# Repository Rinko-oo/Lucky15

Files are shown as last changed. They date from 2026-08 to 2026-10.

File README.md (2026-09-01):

# Lucky15
15 key + rotary encoder macropad for media control and macros

## CAD


## PCB



## Schematic


## BOM
This is everything needed to build the Lucky15, currently all available on AliExpress\
**NOTE** - Welcome deal was applied to the Milky Yellow switches
| Qty | Part | Link | Cost (CAD) |
| --- | ---- | ---- | --- |
| 1 | NRF52840 | [Link](https://www.aliexpress.com/item/1005007205026373.html) | $6.09 |
| 15 | Gateron Milky Yellow Switches | [Link](https://www.aliexpress.com/item/1005007039372956.html) | $1.41 |
| 1 | Polymer Lithium Battery 600mAh | [Link](https://www.aliexpress.com/item/1005007905669396.html) | $11.58 |
| 1 | 0.91 Inch OLED Display | [Link](https://www.aliexpress.com/item/1005008640108394.html) | $3.54 |
| 16 | 1N4148 Diodes | [Link](https://www.aliexpress.com/item/1005009379098965.html) | $4.29 |
| 2 | 2.54mm Silver Headers | [Link](https://www.aliexpress.com/item/4001122376295.html) | $3.79 |
| 15 | Blank Keycaps | [Link](https://www.aliexpress.com/item/1005007683242914.html) | $8.79 |
| 1 | EC11 Rotary Encoder | [Link](https://www.aliexpress.com/item/1005004908084537.html) | $6.24 |
| 1 | PCB | [Link](https://jlcpcb.com/) | $11.18 |
| 1 | MSK12C02 Switch | [Link](https://www.aliexpress.com/item/4000685483225.html) | $3.59 |
|  |  | **Total** | **$60.50** |

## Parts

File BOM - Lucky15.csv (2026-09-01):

Item | Link | Price
NRF52840 | https://www.aliexpress.com/item/1005007205026373.html?mp=1 | $6.09
Gateron Milky Yellow Switches (50 Pcs) | https://www.aliexpress.com/item/1005007039372956.html?mp=1 | $1.41
Polymer Lithium Battery 600mAh | https://www.aliexpress.com/item/1005007905669396.html?mp=1 | $11.58
0.91 Inch OLED Display | https://www.aliexpress.com/item/1005008640108394.html?mp=1 | $3.54
1N4148 Diodes (50 Pcs) | https://www.aliexpress.com/item/1005009379098965.html?mp=1 | $4.29
2.54mm Silver Headers | https://www.aliexpress.com/item/4001122376295.html?mp=1 | $3.79
Blank Keycaps (20 Pcs) | https://www.aliexpress.com/item/1005007683242914.html?mp=1 | $8.79
EC11 Rotary Encoder (5 Pcs) | https://www.aliexpress.com/item/1005004908084537.html?mp=1 | $6.24
PCB | https://cart.jlcpcb.com/shopcart/cart/ | $11.18
MSK12C02 Switch (50 Pcs) | https://www.aliexpress.com/item/4000685483225.html | $3.59
Total |  | $60.50

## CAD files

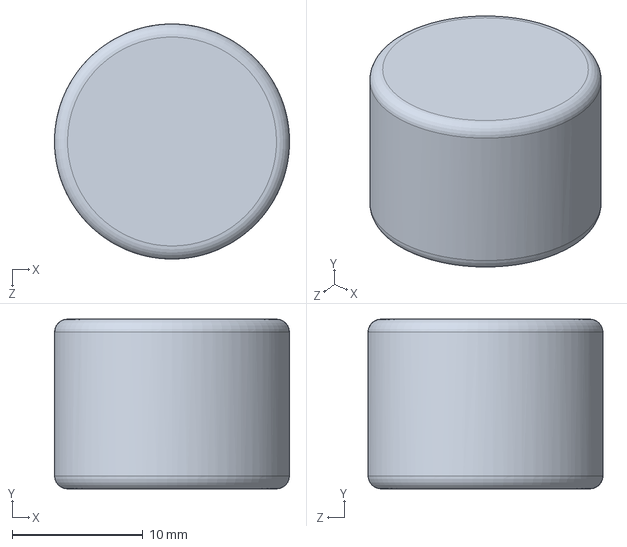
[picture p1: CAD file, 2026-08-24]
cad/spookynob.SLDPRT
18.0 x 13.0 x 18.0 mm

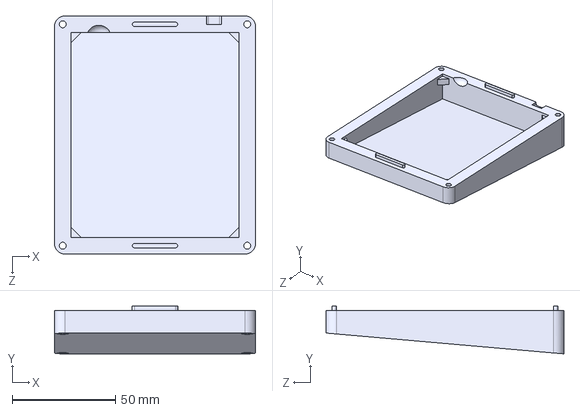
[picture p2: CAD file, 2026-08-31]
production/Case Bottom.STEP
97.2 x 23.1 x 115.0 mm

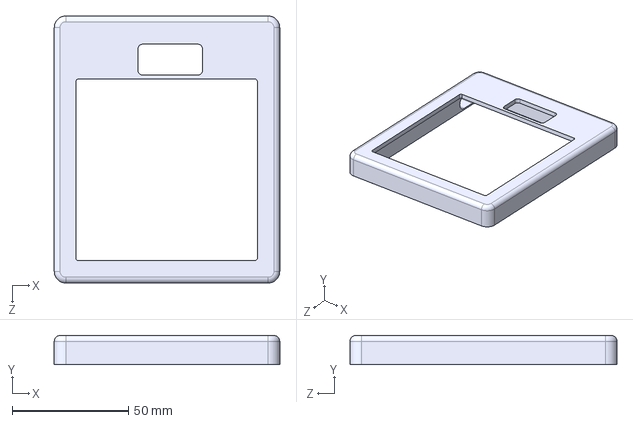
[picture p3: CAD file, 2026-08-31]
production/Case Top.STEP
97.2 x 12.5 x 115.0 mm

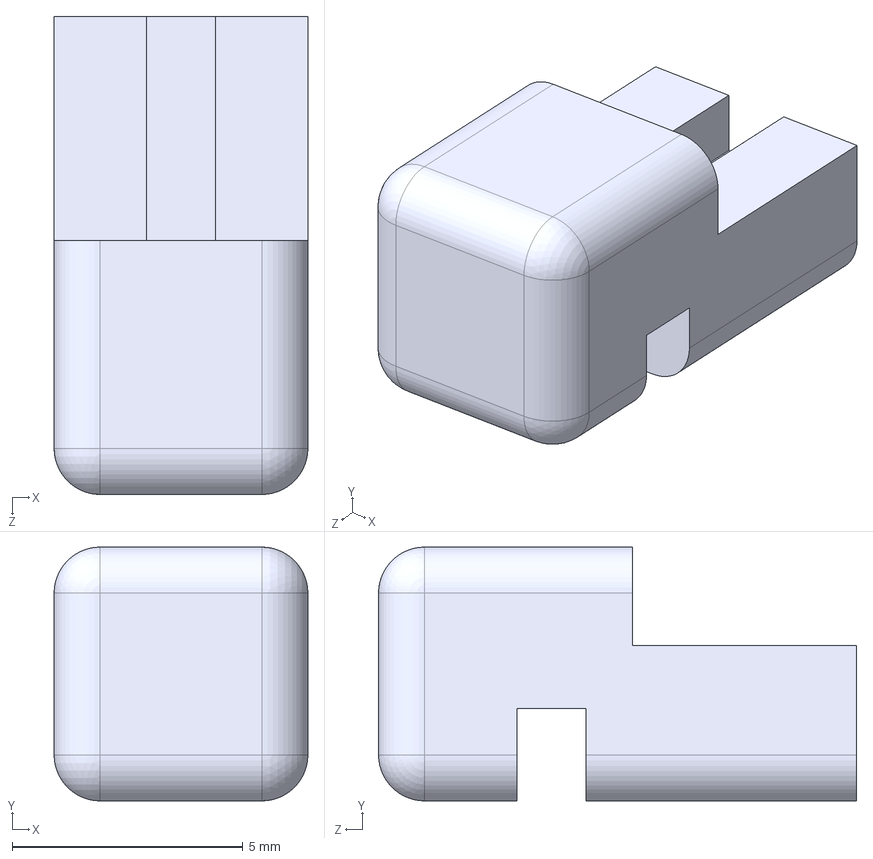
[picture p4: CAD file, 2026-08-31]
production/Power Switch.STEP
5.50 x 5.50 x 10.4 mm

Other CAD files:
production/spookynob.STEP

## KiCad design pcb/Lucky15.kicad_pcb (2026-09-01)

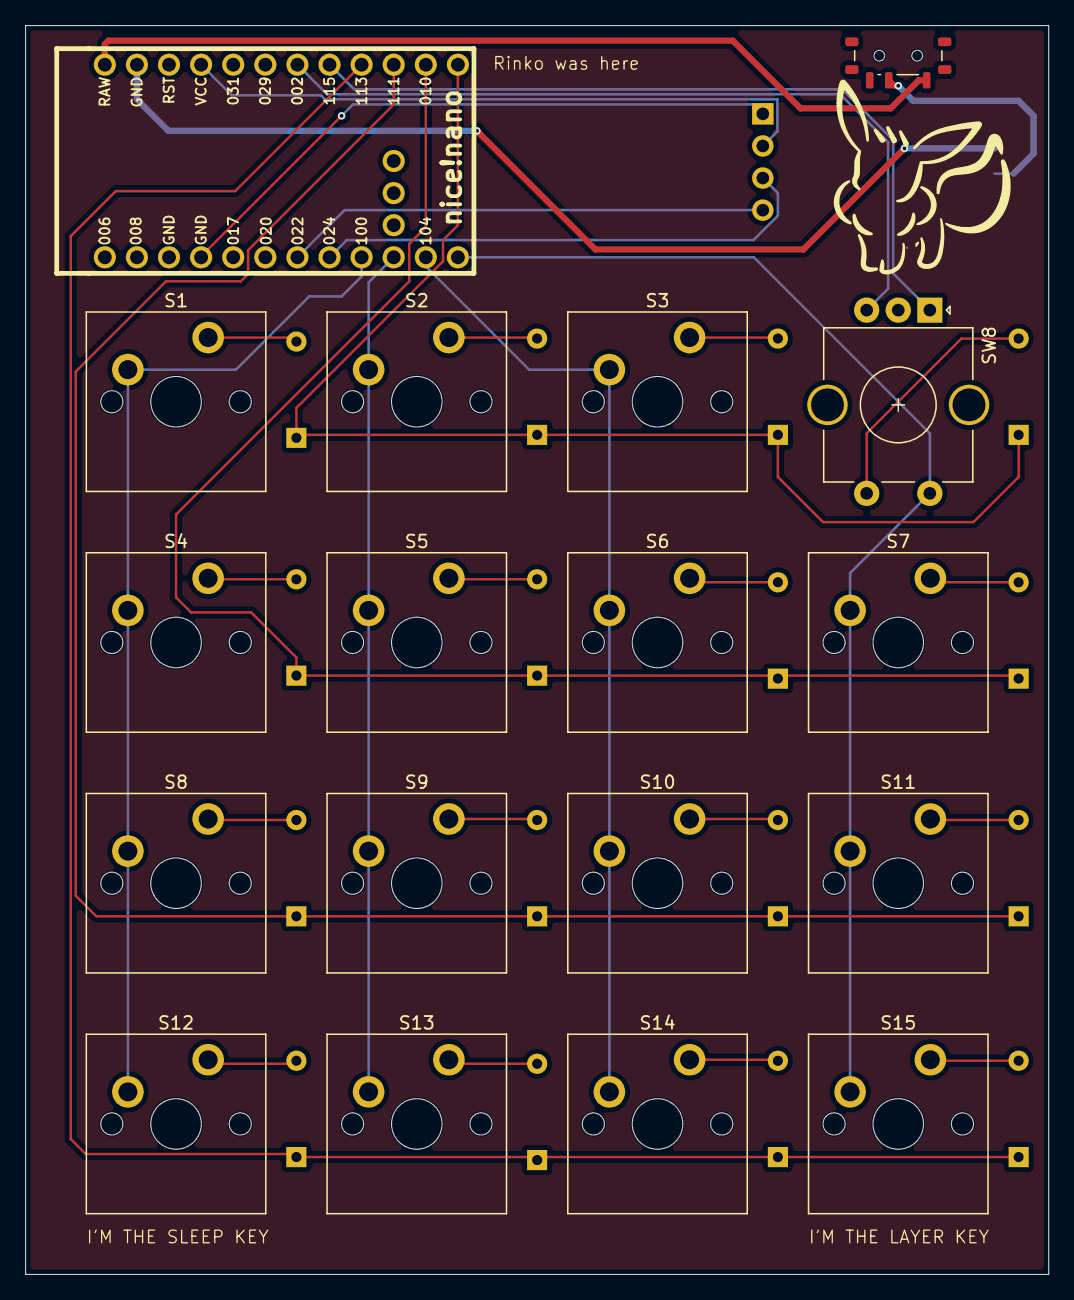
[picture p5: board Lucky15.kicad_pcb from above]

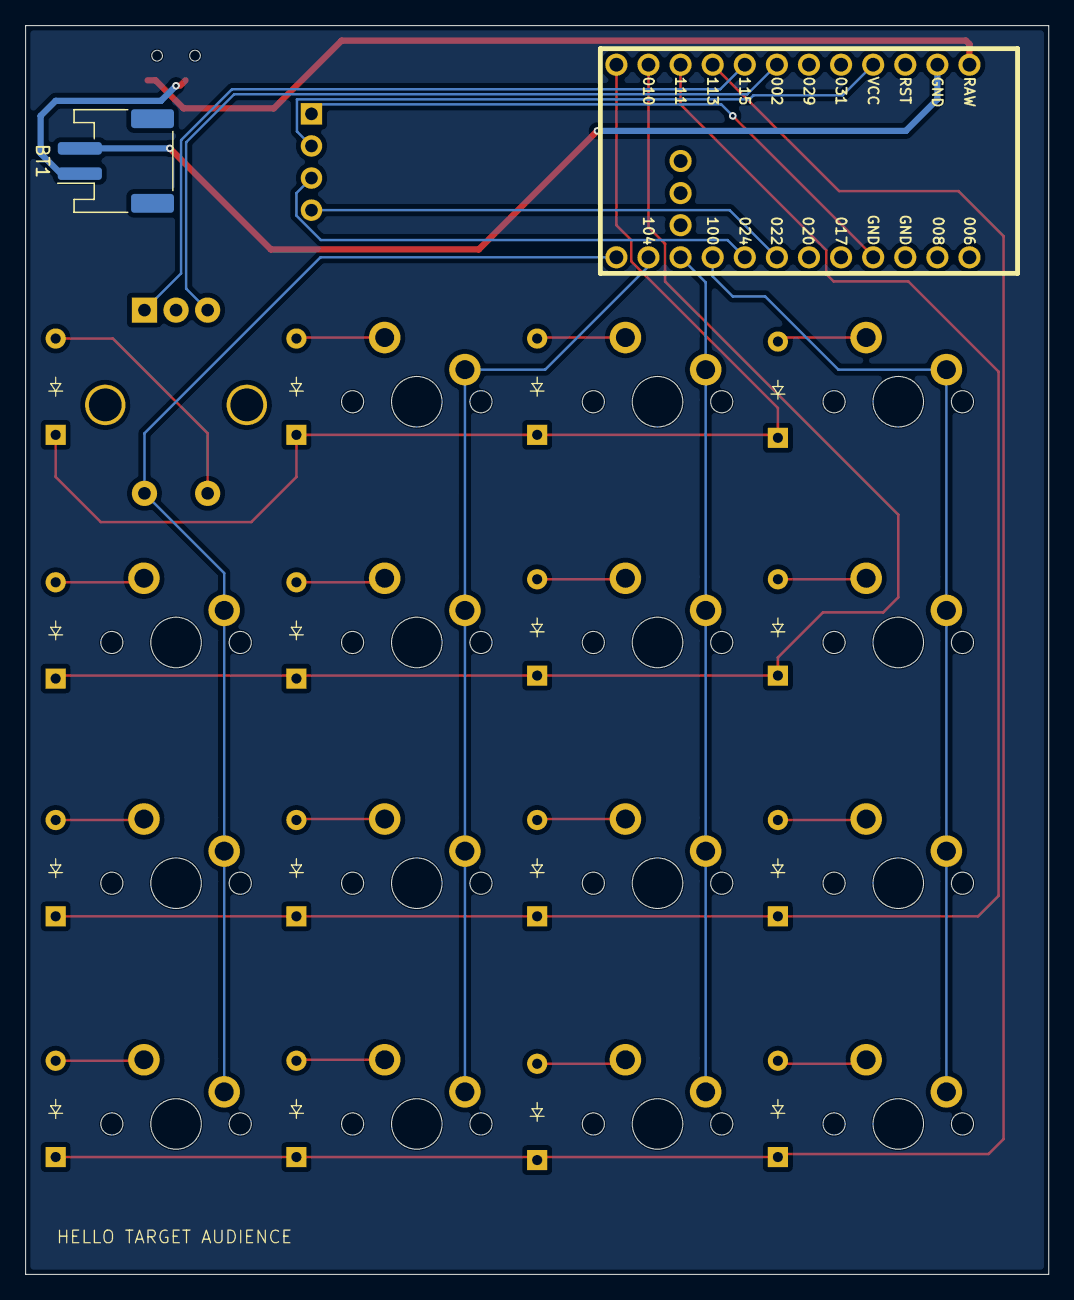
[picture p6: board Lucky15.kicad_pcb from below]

Board: 2 copper layers, 81.0 x 98.8 mm, 36 parts (17 on the bottom side), 33 nets.

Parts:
BT1: Battery; JST_PH_S2B-PH-SM4-TB_1x02-1MP_P2.00mm_Horizontal
D1, D2, D3, D4, D5, D6, D7, D8, D9, D10, D11, D12, D13, D14, D15, D16: Diode_DO-35
J1: OLED_128x32
S1, S2, S3, S4, S5, S6, S7, S8, S9, S10, S11, S12, S13, S14, S15: MX_PCB_1.00u
SW1: SW_SPDT; SW_SPDT_Shouhan_MSK12C02
SW8: RotaryEncoder_Switch; RotaryEncoder_Alps_EC11E-Switch_Vertical_H20mm_CircularMoun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
U1: ProMicro; nice_nano

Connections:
BATT+: SW1.1 (A), U1.24 (RAW)
BATT-: BT1.2 (-), U1.23 (GND)
Column 0: S1.1, S4.1, S8.1, S12.1, U1.9 (6/D7)
Column 1: S2.1, S5.1, S9.1, S13.1, U1.10 (7/E6)
Column 2: S3.1, S6.1, S10.1, S14.1, U1.11 (8/B4)
Column 3: S7.1, S11.1, S15.1, SW8.S2, U1.12 (9/B5)
ENCO_A: SW8.A, U1.17 (F7/A0)
ENCO_B: SW8.B, U1.18 (F6/A1)
unnamed: BT1.1 (+), SW1.2 (B)
unnamed: D1.2 (A), S1.2
unnamed: D2.2 (A), S2.2
unnamed: D3.2 (A), S3.2
unnamed: D4.2 (A), S4.2
unnamed: D5.2 (A), S5.2
unnamed: D6.2 (A), S6.2
unnamed: D7.2 (A), S7.2
unnamed: D8.2 (A), S8.2
unnamed: D9.2 (A), S9.2
unnamed: D10.2 (A), S10.2
unnamed: D11.2 (A), S11.2
unnamed: D12.2 (A), S12.2
unnamed: D13.2 (A), S13.2
unnamed: D14.2 (A), S14.2
unnamed: D15.2 (A), S15.2
unnamed: D16.2 (A), SW8.S1
OLED_GND: J1.1 (GND), U1.4 (GND)
OLED_SCL: J1.3 (SCL), U1.8 (5/C6)
OLED_SDA: J1.4 (SDA), U1.7 (4/D4)
OLED_VCC: J1.2 (VCC), U1.21 (VCC)
Row 0: D1.1 (K), D2.1 (K), D3.1 (K), D16.1 (K), U1.13 (B6/10)
Row 1: D4.1 (K), D5.1 (K), D6.1 (K), D7.1 (K), U1.14 (B2/16)
Row 2: D8.1 (K), D9.1 (K), D10.1 (K), D11.1 (K), U1.15 (B3/14)
Row 3: D12.1 (K), D13.1 (K), D14.1 (K), D15.1 (K), U1.16 (B1/15)

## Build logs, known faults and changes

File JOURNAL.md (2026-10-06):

---
Title: Lucky15
Author: William
Description: 15 key + rotary encoder macropad for media control and macros
Created: 2026-07-15
---

# July 15th - Starting Out
- Decided on a 4x4 macropad with 15 keys and a rotary encoder
- The 3 Switches at the top are to be previous track, pause/play, and next track
- Rotary encoder for turning up and down the volume & mute button
- Remaining 12 switches for macros and shortcuts
- Started off with the [Hackpad Guide](https://hackpad.hackclub.com/guide)
- Got recommended the [NRF52840](https://www.aliexpress.com/item/1005007205026373.html)\
\
First iteration of the schematic
- Looked super simple so I decided to add a few things
- 0.91 Inch OLED screen to display currently playing media
- 110 mAh battery so I can use it wirelessly like a remote control
- I only had enough pins for the encoder and switches, not enough for the OLED display
- Was referred to this [Joe Scotto tutorial](https://youtu.be/8WXpGTIbxlQ?si=8FqVbhXCCD7eRLAT) and switched to using diodes like he does
\
Current iteration of the schematic

Hours spent: ~2.5 Hours

# July 17th - The PCB
- Updated PCB from schematic and dragged all the components into place
- Had the wrong footprint so I just got the nice!nano footprint since the difference between the NRF52840 and the nice!nano isn't applicable to my use case
- I have to flip the OLED screen upside down but it should be a quick firmware tweak to make it display things upright to user
- Battery mounts under the pcb so the wire doesn't get in the way and I don't have to cluster everything on the top
- Tried to run traces as cleanly as possible\
\
PCB without filled zones\
\
PCB with filled zones
- Case is next

Hours spent: ~1.5

# July 24th - Case Bottom
- I'm used to Onshape but I want to learn SolidWorks since I'm going to University and will probably have to learn it anyway so the sooner the better
- There was a massive learning curve starting out but I figured out the shortcuts in the end
- Assembly was definitely a pain to work with and I struggled with the mates for a while
- Got a mockup of the bottom going
\
Top View\
\
Side/Bottom View
- Discovered that with my setup I can stuff a much larger battery inside
- Going for one around the 500 mAh area (5mm tall)
- Probably going to use velcro or double sided tape to fix it to the bottom of the case
- The walls look kind of weak and I have to figure out how to actually fix the pcb into the case but that is another day's problem

Hours spent: ~2.5

# August 3rd - Case Top + Nob
- Widened the side walls to 8mm
- Filleted edges out so that it's more comfortable to use
- Covered the MCU and empty PCB space
- Planning on putting a design there and maybe an easter egg on the inside but I can't think of anything
\
Current State
- Planning on using 4 M3 screws to hold it together but I need to test out the self-tapping first because I don't trust it yet.

Hours spent: ~2

# August 13th - Firmware
- Started out the firmware with the ZMK documentation
- Heard that doing it inside an already existing repo would be a struggle so I made [another one](https://github.com/Rinko-oo/Lucky15-zmk-config)
- 3 keymaps
- Default for macros and miscellaneous binds
- Numpad for numbers
- Settings for managing bluetooth and flashing new firmware, mainly utility
- Next is putting designs on the case & figuring out how to draw on the OLED display

Hours spent: ~1.5

# August 21st - Tweaks
- Forgot to put a hole for the usb-c port so I added that
- Made it extra wide to accommodate fatter cables
- Added tabs to align the case so I wouldn't be misalign the case when making the threads. There is one one the top and one at the bottom.
\
Top Tab\
\
Usb-c hole

Hours spent: ~0.5

# August 23rd - First Submission
- Compiled every part needed into spreadsheet
- Everything is from AliExpress and the PCB is from JLCPCB
- Updated readme with the list of parts & links
- Also updated firmware since I forgot to put an on/off switch so I can save battery by putting it into deep sleep
- PCB will be 1.6mm thick instead of 1.5 as the CAD suggests so I will tweak for that later
- Case will be 3D printed
\
Google Sheet of items to buy

Hours spent: ~1.5

# August 31st - On/Off Switch & Submission
- I forgot to add an on/off switch after I decided to add a battery
- Added it to the schematic and put it on the top right of the board\

- The walls of the macropad are very thick so I made a new part to make it easy to turn on and off
\
- I'm not sure as to its effectiveness but in my head it works fine
- Updated BOM as the prices on Aliexpress fluctuate for some reason

Hours spent: ~3

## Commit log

2026-07-09 Create Journal.md
    Create journal to track progress
2026-07-16 Newer schematic image
    Didn't realize that the schematic screenshot didn't have the battery yet
2026-07-18 July 17th Journal Entry
    PCB stuff
2026-07-25 July 24th Entry
    Got the bottom of the case going
2026-08-04 August 3rd Entry
    Case top + nob
2026-08-23 Squashed 'Firmware/' changes from 7b7c1c5..5005dad
    5005dad Add soft off switch to menu keymap since I don't have a switch
    git-subtree-dir: Firmware
    git-subtree-split: 5005dadf3dcaee0d687e26467ac7968920822f32
2026-08-24 Update README with images and BOM
    Updated prices and links in the BOM section.
2026-08-24 Uploading files and BOM
    [Lucky15 BOM.csv, Lucky15.kicad_pcb, Lucky15.kicad_sch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]
2026-08-24 Add gerber to production
2026-08-24 Polishing file structure
    [bom.csv, designators.csv, positions.csv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]
2026-08-31 New Gerber
2026-08-31 Add on/off switch and update BOM
    [Case Bottom.STEP, Case Top.STEP, Lucky15 BOM.csv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]
2026-08-31 Update BOM Total in README
2026-09-01 Update PCB Uploads to current version with power switch
    [Lucky15.kicad_pcb, Lucky15.kicad_sch]
2026-09-01 Update README PCB images
    Added new images to PCB and Schematic sections in README.
2026-09-01 Rename BOM file
    [BOM - Lucky15.csv]
